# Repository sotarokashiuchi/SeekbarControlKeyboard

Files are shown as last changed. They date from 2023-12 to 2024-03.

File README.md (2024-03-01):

# SeekbarControlKeyboard
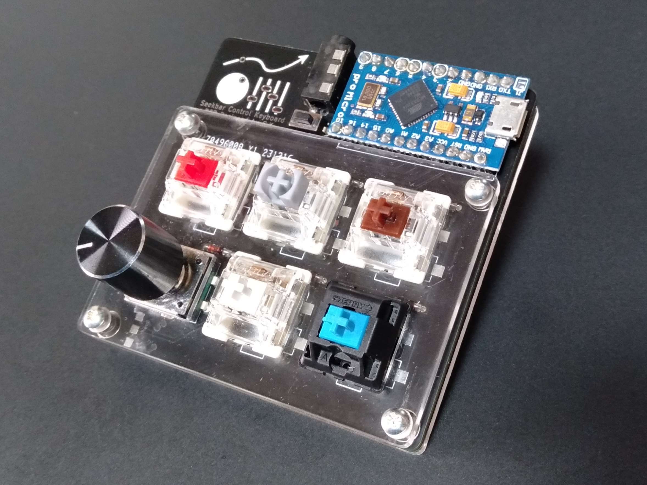
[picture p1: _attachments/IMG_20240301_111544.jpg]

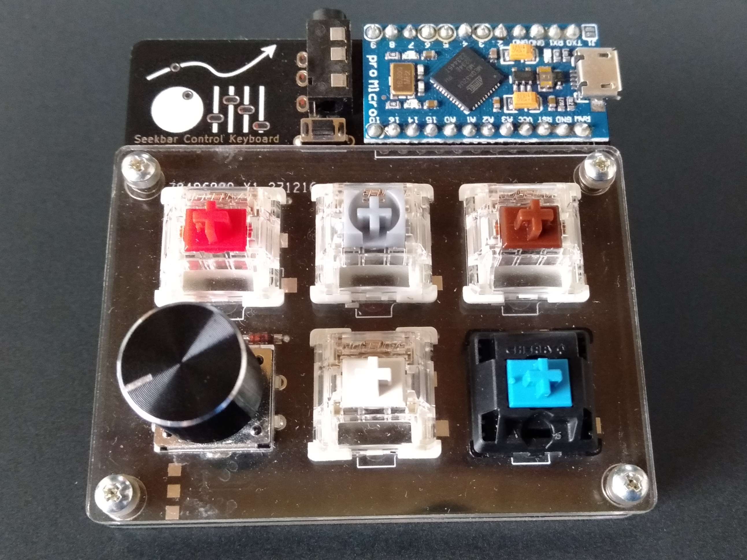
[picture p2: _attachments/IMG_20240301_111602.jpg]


## 概要
- シークバー(音楽の再生、停止、スキップなど)を制御するためのキーボード
- 5スイッチ、1ロータリーエンコーダ(ボタン付き)
- 分割キーボード対応
- LED対応
- 完全オープンで、各自発注可能

## デフォルトキーマップ
```
┌───┬───┬───┐
│ A │ B │ C │ // Aはロータリーエンコーダ
├───┼───┼───┤
│ D │ E │ F │
└───┴───┴───┘
```

| key | single tap | double tap | other action |
| --- | --- | --- | --- |
| A | | | 回転で音量調節 |
| B | ファンクションキー | | |
| C | デバイスをスリープ | | |
| D | 少し戻る | 前のトラックへ | |
| E | 一時停止/再生 | | |
| F | 少し進む | 次のトラックへ | |

## 部品
| parts | counts | sample value(en) |
| --- | --- | --- |
| PCB | 1 | 88 |
| アクリル版 | 1 | 310 |
| ProMicro | 1 | 770 |
| ダイオード | 6 | 10 |
| キースイッチ | 5 | 350 |
| ロータリーエンコーダ(EC12) | 1 | 330 |
| PCBソケット | 5 | 94 |
| タクトスイッチ | 1 | 22 |
| M2ボルト(12.6mm以上) | 4 | |
| M2ナット(2mm) | 8 | 35 |
| -- options -- | | |
| ノブ | 1 | |
| キーキャップ | 5 | |
| M2ワッシャー(0.5mm) | 8 | 15 |
| クッションゴム | 4 | |
| LEDシート | 1 | 550 |
| ジャック線 | 1 | 330 |
| TRRSジャック(MJ-4PP-9) | 1 | 165 |
| total | | 2167 |
| options total | | 1060 |

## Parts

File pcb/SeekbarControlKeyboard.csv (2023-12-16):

No. | Qnty | Value | Vendor
1 | 1 | PCB基盤
2 | 1 | トッププレート
3 | 1 | ボトムプレート
4 | 1 | ProMicro
5 | 6 | ダイオード
6 | 1 | タクトスイッチ
7 | 2 | TRRSジャック(MJ-4PP-9)
8 | 1 | ジャンク線
9 | 4 | M2スペーサー6.5mm
10 | 8 | M2ネジ4mm
11 | 1 | LEDシート
12 | 4 | クッションゴム
13 | 5 | PCB ソケット CherryMX 用
14 | 5 | PCB ソケット Choc 用
15 | 5 | キースイッチ
16 | 5 | キーキャップ
17 | 1 | ロータリーエンコーダー
18 | 1 | ノブ・つまみ

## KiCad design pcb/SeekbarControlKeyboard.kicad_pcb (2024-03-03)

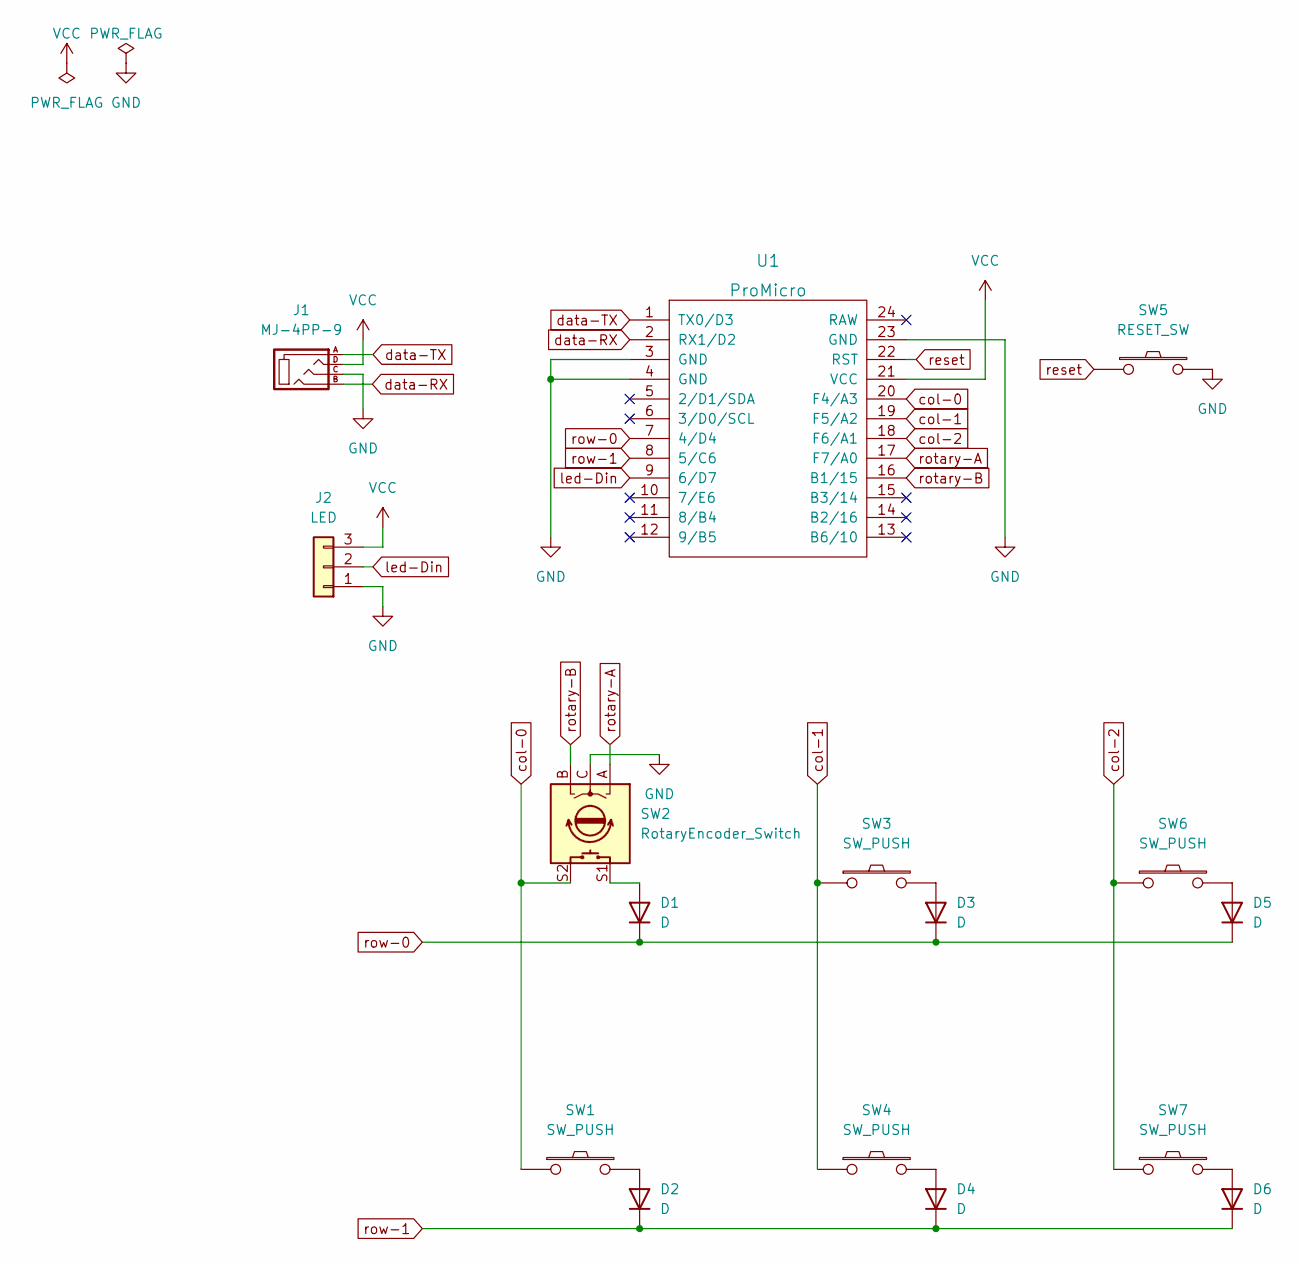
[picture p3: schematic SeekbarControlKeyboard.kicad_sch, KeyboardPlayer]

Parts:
D1, D2, D3, D4, D5, D6: D; D3_TH_SMD_v3
J1: MJ-4PP-9
J2: LED; StripLED_rev
SW1, SW3, SW4, SW6, SW7: SW_PUSH; CherryMX_Choc_Hotswap
SW2: RotaryEncoder_Switch; RotaryEncoder_EC11
SW5: RESET_SW; ResetSW
U1: ProMicro; ProMicro_v2

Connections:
GND: J1.C, J2.1, SW2.C, SW5.2, U1.3 (GND), U1.4 (GND), U1.23 (GND)
unnamed: D1.2 (A), SW2.S1
unnamed: D2.2 (A), SW1.2
unnamed: D3.2 (A), SW3.2
unnamed: D4.2 (A), SW4.2
unnamed: D5.2 (A), SW6.2
unnamed: D6.2 (A), SW7.2
VCC: J1.D, J2.3, U1.21 (VCC)
col-0: SW1.1, SW2.S2, U1.20 (F4/A3)
col-1: SW3.1, SW4.1, U1.19 (F5/A2)
col-2: SW6.1, SW7.1, U1.18 (F6/A1)
data-RX: J1.B, U1.2 (RX1/D2)
data-TX: J1.A, U1.1 (TX0/D3)
led-Din: J2.2, U1.9 (6/D7)
reset: SW5.1, U1.22 (RST)
rotary-A: SW2.A, U1.17 (F7/A0)
rotary-B: SW2.B, U1.16 (B1/15)
row-0: D1.1 (K), D3.1 (K), D5.1 (K), U1.7 (4/D4)
row-1: D2.1 (K), D4.1 (K), D6.1 (K), U1.8 (5/C6)

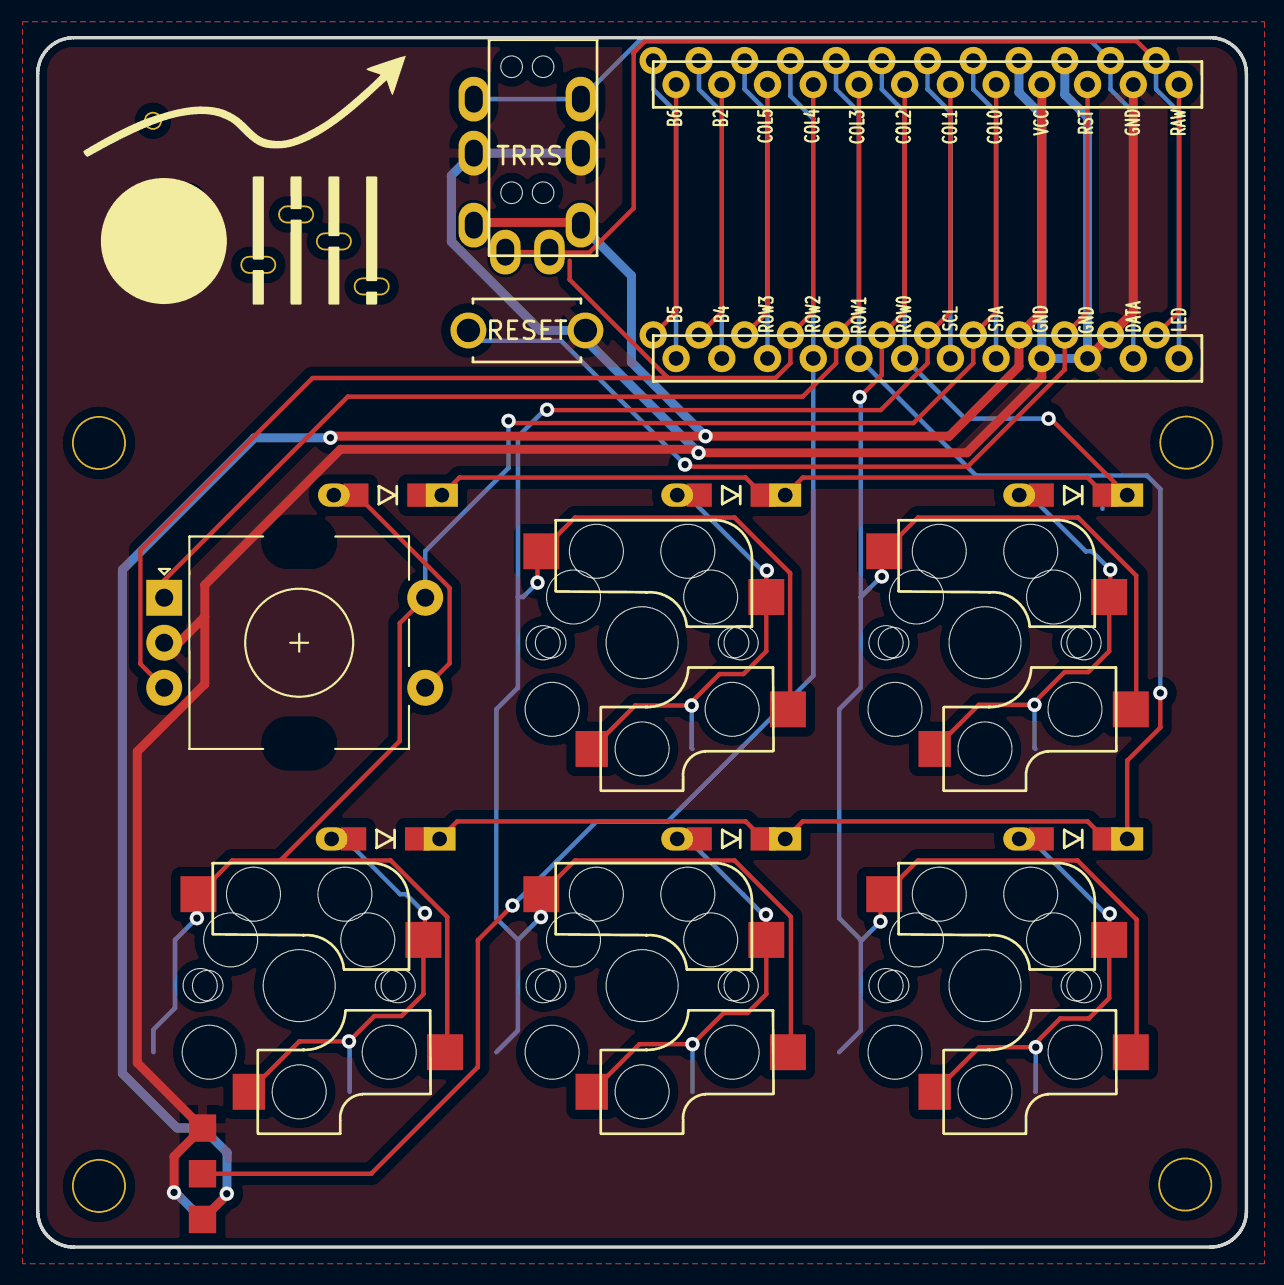
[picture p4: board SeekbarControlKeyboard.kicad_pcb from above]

Board: 2 copper layers, 67.2 x 67.2 mm, 16 parts (0 on the bottom side), 19 nets.

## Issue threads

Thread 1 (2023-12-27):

試作品フィードバック

sotarokashiuchi, 2023-12-27:
# PCB、電子部品到着
- GND塗りつぶし出来ているのか?
- ジャック線部分、少し緩い
- エンコーダにノブがついてきた
- エンコーダ、ノンクリックの方が、マウスとして使うならよいかも
- 基板のM2ネジ用のホール大きすぎる

sotarokashiuchi, 2024-03-01:
修正できる問題点を修正

Closed 2024-03-01.

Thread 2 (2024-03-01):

PCB、プレート 固定方法変更

sotarokashiuchi, 2024-03-01:
# 問題点
- [x] PCBのM2ネジのサイズが間違っている
- [x] PCBのネジ穴が大きすぎる
- [x] プレートが上下に動いてしまう
- [ ] M2ネジの流通量が少ない
- [x] スペーサーが高価

sotarokashiuchi, 2024-03-01:
# 改善策
- ボルトとナット、ワッシャーで固定する
- ナットの固定部分が飛び出るのを防ぐ方法
  - 最適なボルトを選ぶ必要がある(12.6mmが最適)
  - PCBで固定し、プレー部分に固定部を作らない
  - 頭が薄型のボルトを使用する

Closed 2024-03-01.

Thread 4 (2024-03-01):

フットプリントのライブラリ化

sotarokashiuchi, 2024-03-01:
# 内容
- 現在のフットプリントのライブラリはローカルのパスで通っている
- GitHubに公開するに当たり、相対パスでアクセスできるように変更する必要がある
- またダイオードのフットプリントのシルクが両面に印字されていないので、修正する
- #1

sotarokashiuchi, 2024-03-01:
# 解決策
- Kicad上で`${KIPRJMOD}`を使うと相対パスを利用できる
- フットプリント、シンボルの両方のライブラリを相対パスに以降
- githubで公開されているライブラリを使う場合は、gitのsubmoduleを使った
- ダイオードのフットプリンの問題も修正した

Closed 2024-03-01.

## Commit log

2023-12-06 first schematic
    [MinimumKeyboard.kicad_pcb, MinimumKeyboard.kicad_sch]
2023-12-06 footprint assignment
    [MinimumKeyboard.kicad_sch]
2023-12-11 complete PCB
    [MinimumKeyboard.kicad_pcb, MinimumKeyboard.kicad_sch]
2023-12-11 initilize keboard player
    [KeyboardPlayer.kicad_pcb, KeyboardPlayer.kicad_sch]
2023-12-12 complete SCD
    [KeyboardPlayer.kicad_sch]
2023-12-12 assingnment footpring of parts
    [KeyboardPlayer.kicad_sch]
2023-12-13 complete DRC
    [KeyboardPlayer.kicad_pcb, KeyboardPlayer.kicad_sch]
2023-12-13 add M2
    [KeyboardPlayer.kicad_pcb]
2023-12-14 paint GND
    [KeyboardPlayer.kicad_pcb]
2023-12-14 finished version1.0
    [KeyboardPlayer.kicad_pcb]
2023-12-15 PCB 発注
2023-12-15 rename file and folder
    [SeekbarControlKeyboard.kicad_pcb, SeekbarControlKeyboard.kicad_sch]
2023-12-15 create case file
2023-12-15 add case of keycap
2023-12-15 add case of rotary encoder
2023-12-16 finished plate of bottom and top
    [SeekbarControlKeyboard.kicad_pcb]
2023-12-16 parts list
    [SeekbarControlKeyboard.csv]
2023-12-16 add parts list
    [SeekbarControlKeyboard.csv]
2024-01-06 290mm*500mmのアクリル版用のデータを作成
2024-02-15 update case
2024-03-01 move folder
    [MinimumKeyboard.kicad_pcb, MinimumKeyboard.kicad_sch, SeekbarControlKeyboard.csv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]
2024-03-01 fix M2 PCB close #2
    [SeekbarControlKeyboard.kicad_pcb]
2024-03-01 exchange rotary encoder and switch
    [SeekbarControlKeyboard.kicad_pcb, SeekbarControlKeyboard.kicad_sch]
2024-03-03 move folder and fix Diode fotprint close #4
    [SeekbarControlKeyboard.kicad_pcb, SeekbarControlKeyboard.kicad_sch]
